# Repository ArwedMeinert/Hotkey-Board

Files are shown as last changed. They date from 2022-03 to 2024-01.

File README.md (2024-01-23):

# Hotkey-Board
All the needed Information for the Hotkey-Board
It includes the Schematics of the Hardware, the PCB- Layout and the Code for the actual microcontroller. 
Feel free to make your own changes and improve on what’s already there. 
All the uploaded Files (excluding the libraries in the Arduino IDE) were created by me.

After the design of the PCB, I got it made and soldert all parts on it. Luckily, everything worked at the first try.

The PCB of the Hotkey Board

Each button can be individually programmed. You can add more than one profile and add an individual colour to each profile (every button is individually backlit and be individually addressed). A button press gets visualized by the sudden change of colour, that then fades back to the standard colour of the profile within 200 ms (this also helps with the debounce time of the buttons).

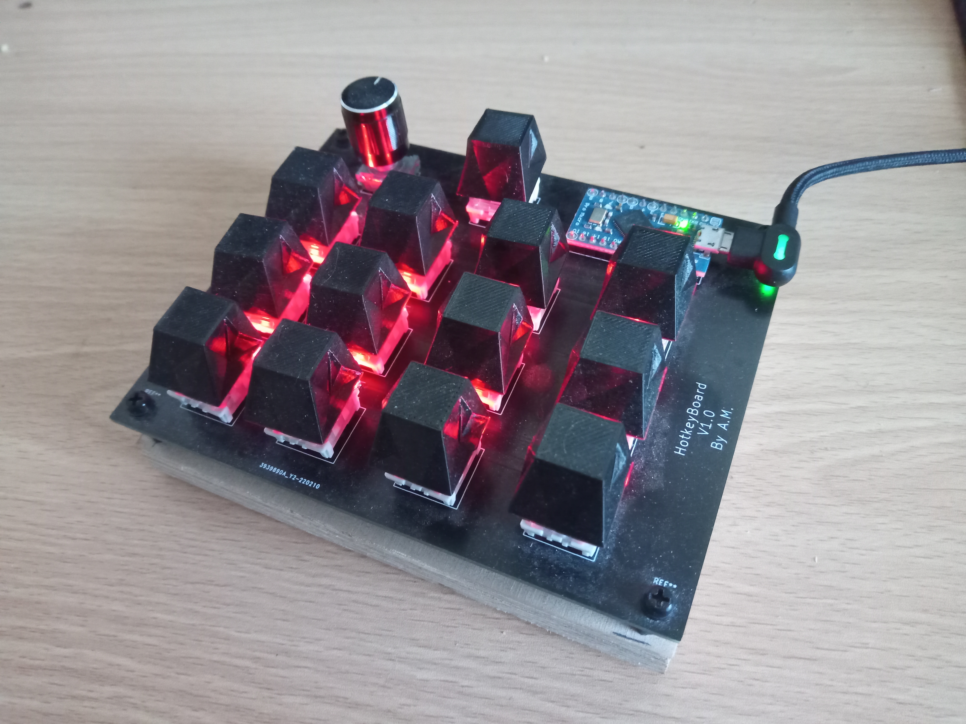
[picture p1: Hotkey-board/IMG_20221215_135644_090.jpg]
The PCB of the Hotkey Board


This version of the Hotkey-Board doesn't support anti-ghosting (using diodes for the button matrix). This could be an improvement left for a second version as well as a little OLED display to display various functions of the keys. 
## Case
After a few months in use I descided to add a case for the pcb to make it easier to carry around (and because I got access to a 3D Printer).

Case of the Board

All the files are available to download. The case now also includes holes for the hinges as well as magnets embedded in the lid to make it stay closed but still easy enough to open.

Case with the Board turned on

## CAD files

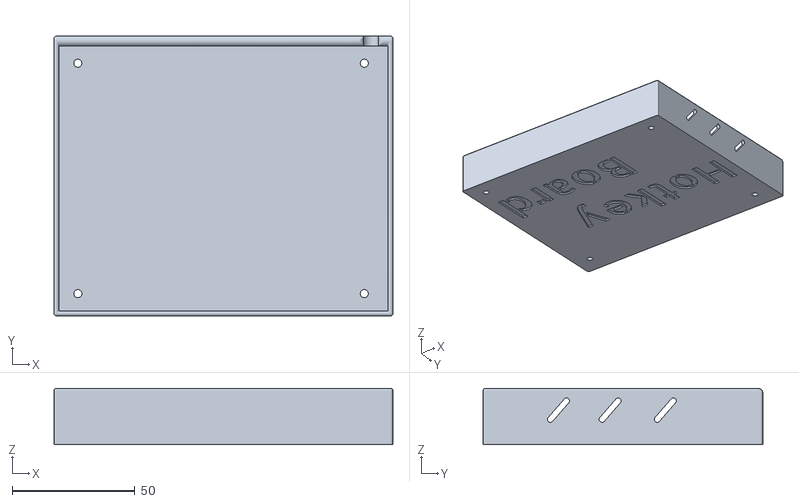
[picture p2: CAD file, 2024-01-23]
HotkeyBoard Case/Part Studio 1 - Part 2.stl
138.3 x 114.1 x 23.0

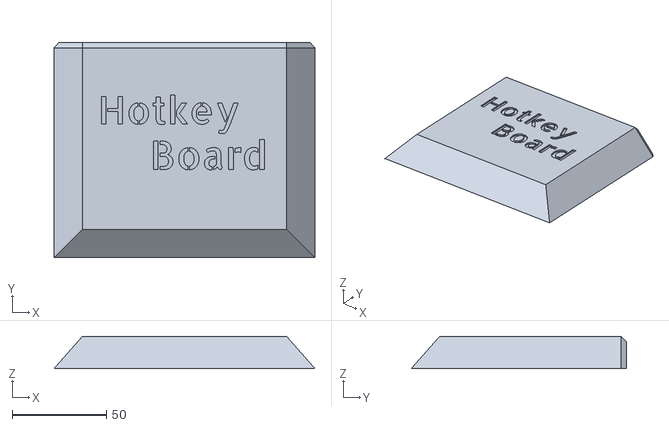
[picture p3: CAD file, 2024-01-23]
HotkeyBoard Case/LowerPart.stl
138.3 x 114.1 x 17.0

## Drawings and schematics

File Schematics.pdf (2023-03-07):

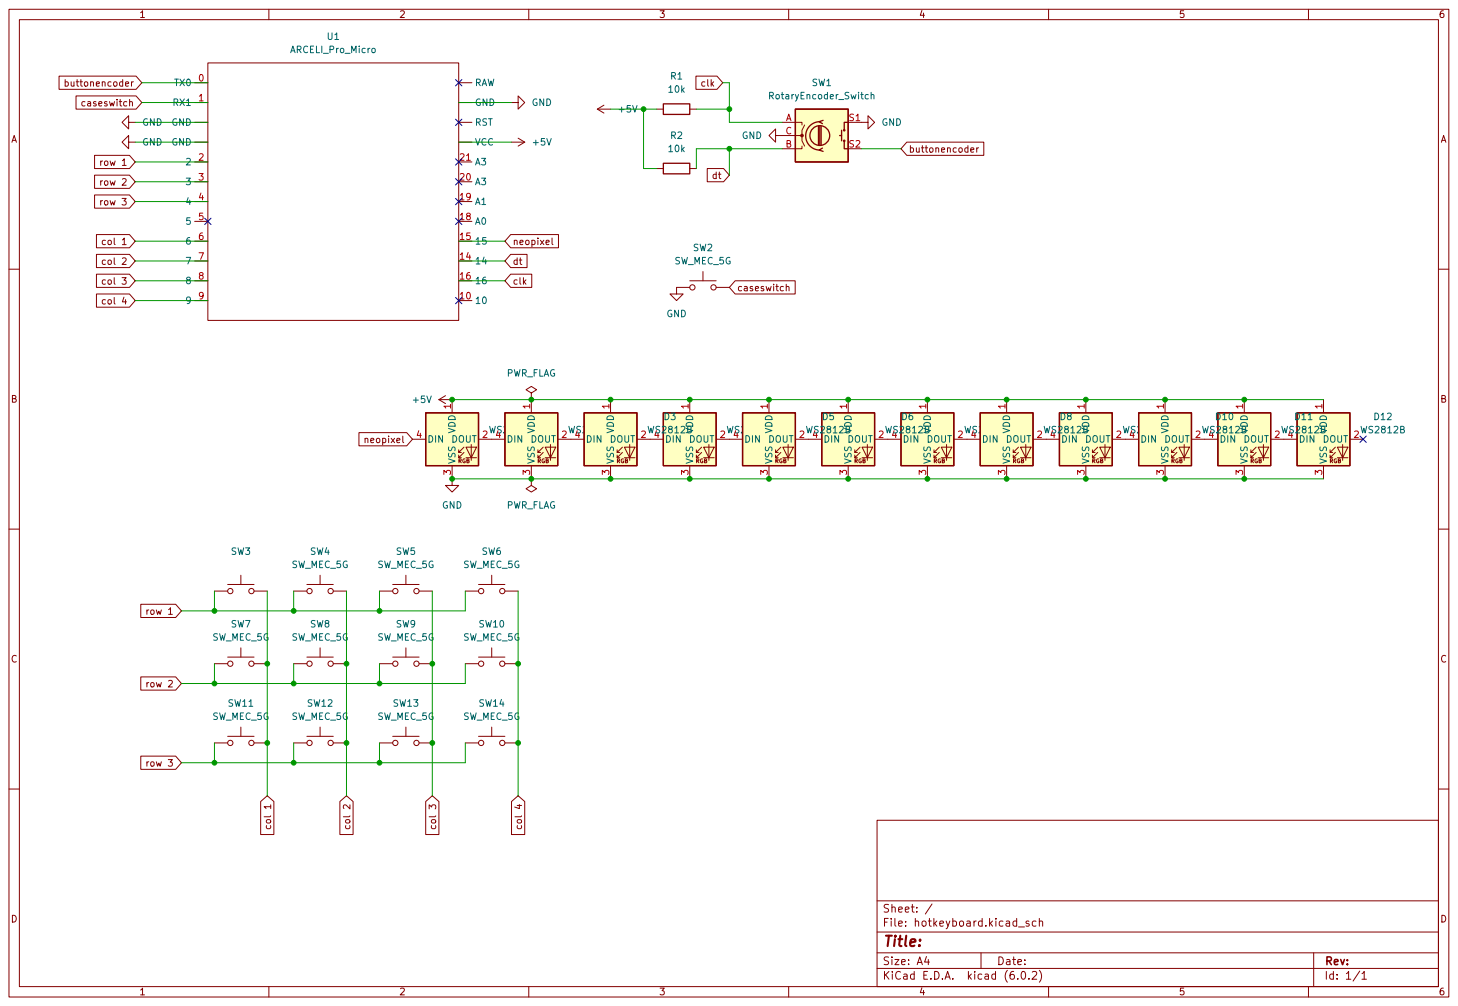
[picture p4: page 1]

3 DIN 4 D3 WS2812B GND GND GND
GND

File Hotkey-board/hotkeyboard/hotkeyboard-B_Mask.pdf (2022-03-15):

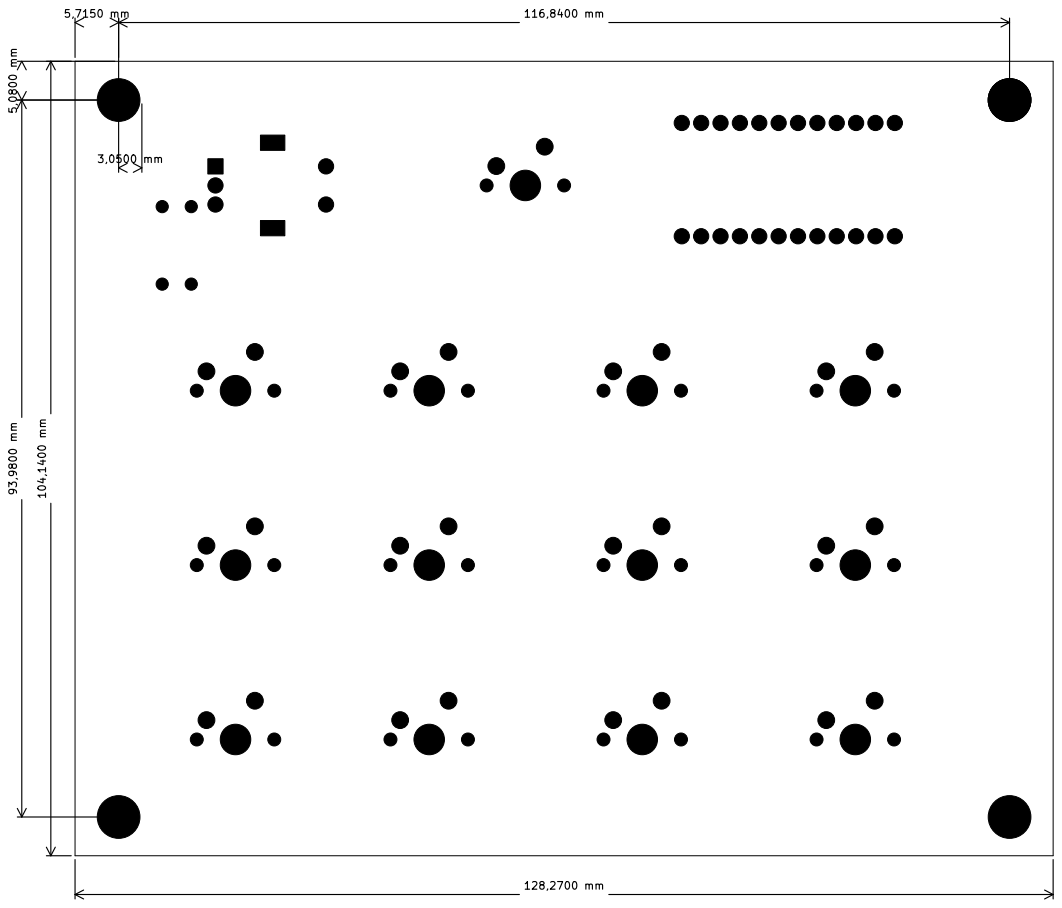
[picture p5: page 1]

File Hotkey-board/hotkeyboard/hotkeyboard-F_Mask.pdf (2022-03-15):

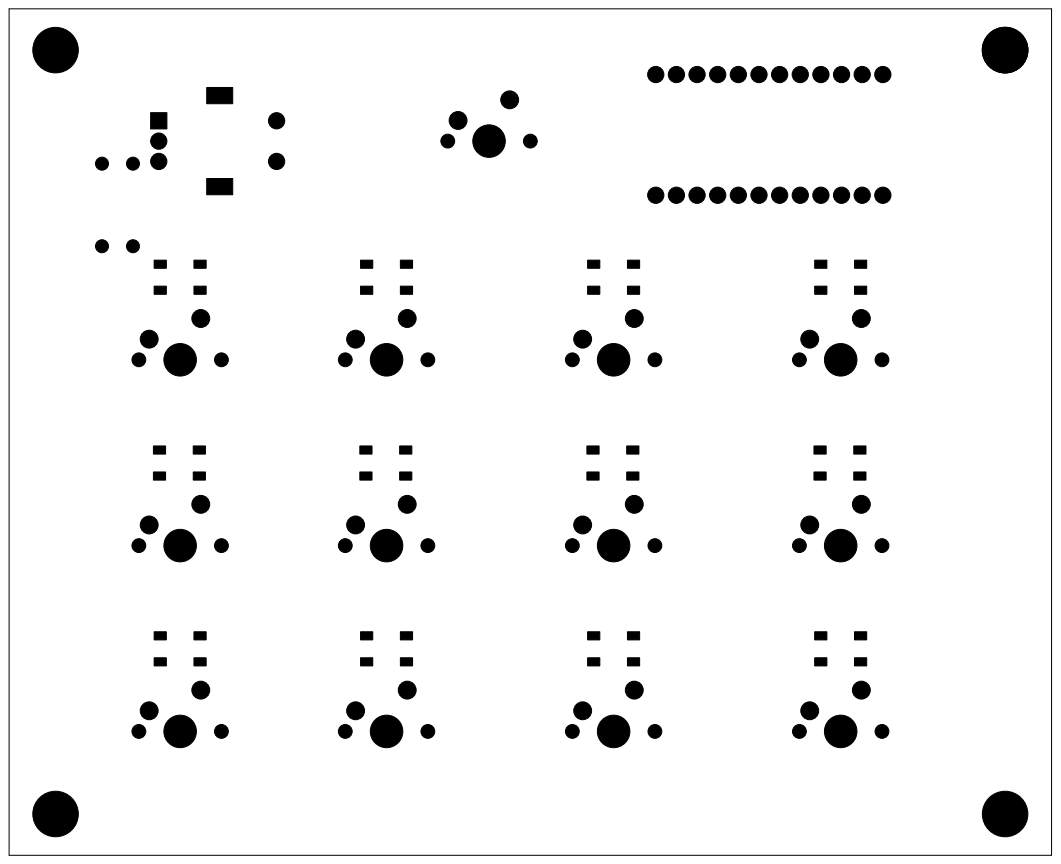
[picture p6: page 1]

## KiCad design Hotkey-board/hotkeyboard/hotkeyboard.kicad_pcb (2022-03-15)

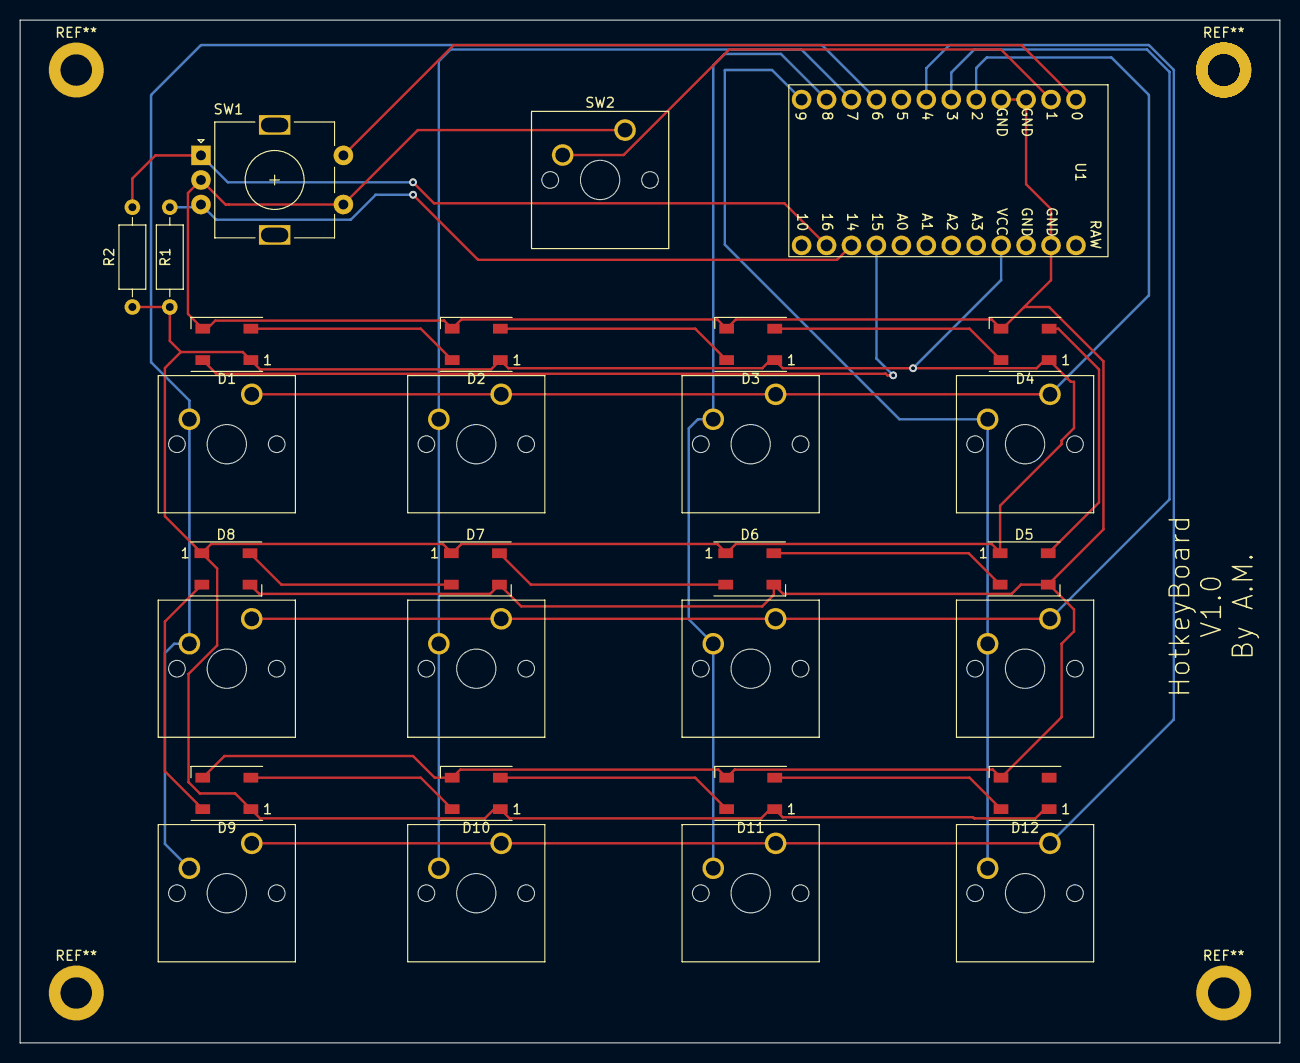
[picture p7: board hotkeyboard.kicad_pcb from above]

Board: 2 copper layers, 128.3 x 104.1 mm, 17 parts (0 on the bottom side), 18 nets.

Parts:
D1, D2, D3, D4, D5, D6, D7, D8, D9, D10, D11, D12: WS2812B; LED_WS2812B_PLCC4_5.0x5.0mm_P3.2mm
R1, R2: R_Axial_DIN0207_L6.3mm_D2.5mm_P10.16mm_Horizontal
SW1: RotaryEncoder_Switch; RotaryEncoder_Alps_EC11E-Switch_Vertical_H20mm
SW2: SW_MEC_5G; SW_Cherry_MX_1.00u_PCB
U1: ARCELI_Pro_Micro; ARCELI ATmega32U4

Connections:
+5V: D1.1 (VDD), D2.1 (VDD), D3.1 (VDD), D4.1 (VDD), D5.1 (VDD), D6.1 (VDD), D7.1 (VDD), D8.1 (VDD), D9.1 (VDD), D10.1 (VDD), D11.1 (VDD), D12.1 (VDD), R1.1, R2.1, U1.VCC
GND: D1.3 (VSS), D2.3 (VSS), D3.3 (VSS), D4.3 (VSS), D5.3 (VSS), D6.3 (VSS), D7.3 (VSS), D8.3 (VSS), D9.3 (VSS), D10.3 (VSS), D11.3 (VSS), D12.3 (VSS), SW1.C, SW1.S1, SW2.1, U1.GND
unnamed: D1.2 (DOUT), D2.4 (DIN)
unnamed: D2.2 (DOUT), D3.4 (DIN)
unnamed: D3.2 (DOUT), D4.4 (DIN)
unnamed: D4.2 (DOUT), D5.4 (DIN)
unnamed: D5.2 (DOUT), D6.4 (DIN)
unnamed: D6.2 (DOUT), D7.4 (DIN)
unnamed: D7.2 (DOUT), D8.4 (DIN)
unnamed: D8.2 (DOUT), D9.4 (DIN)
unnamed: D10.2 (DOUT), D11.4 (DIN)
unnamed: D9.2 (DOUT), D10.4 (DIN)
unnamed: D11.2 (DOUT), D12.4 (DIN)
buttonencoder: SW1.S2, U1.0 (TX0)
caseswitch: SW2.2, U1.1 (RX1)
clk: R2.2, SW1.A, U1.16
dt: R1.2, SW1.B, U1.14
neopixel: D1.4 (DIN), U1.15

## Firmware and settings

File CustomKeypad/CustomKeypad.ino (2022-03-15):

#include <Encoder.h>
#include <Mouse.h>
#include <Keyboard.h>
#include <Keypad.h>
#include <Adafruit_NeoPixel.h>
#define PIXEL_PIN    15
#define enablePin 10
#define PIXEL_COUNT 12
Adafruit_NeoPixel pixels(PIXEL_COUNT, PIXEL_PIN, NEO_GRB + NEO_KHZ800);
const int CLK = 16;      // Definition der Pins. CLK an D6, DT an D5.
const int DT = 14;
const int SW = 1;       // Der Switch wird mit Pin D2 Verbunden. ACHTUNG : Verwenden Sie einen interrupt-Pin!
long altePosition = -999;
Encoder meinEncoder(DT, CLK);
const byte COLS = 4;
const byte ROWS = 3; //four rows
//define the cymbols on the buttons of the keypads
char hexaKeys[ROWS][COLS] = {
  {'1', '2', '3', '4'},
  {'5', '6', '7', '8'},
  {'9', 'A', 'B', 'C'}
};
byte rowPins[ROWS] = {2, 3, 4}; //connect to the row pinouts of the keypad
byte colPins[COLS] = {6, 7, 8, 9}; //connect to the column pinouts of the keypad

//initialize an instance of clmakeeymapass NewKeypad
Keypad customKeypad = Keypad( makeKeymap(hexaKeys), rowPins, colPins, ROWS, COLS);
#define modechange 0
int casenr;
#define caseanz 2
long neuePosition;
char customKey;
bool switched;
void setup() {
  pixels.begin();
  Serial.begin(6600);
  pinMode(enablePin, INPUT_PULLUP);
  pinMode(SW, INPUT_PULLUP);
  pinMode(modechange, INPUT_PULLUP);

  // attachInterrupt(digitalPinToInterrupt(modechange), InterruptCase, FALLING);
  Mouse.begin();
  Keyboard.begin();
  int casenr = 1;
  switched = false;
}

void loop() {
  if (digitalRead(modechange) == LOW) {
    casenr = casenr + 1;
    if (casenr > caseanz) {
      casenr = 1;
    }
    switched = true;

  }
  if (enablePin == LOW) {
    Mouse.end();
    Keyboard.end();
  }
  if (casenr == 1) {
    int normaleFarbe1[] = {50, 0, 0};
    int gedrueckteFarbe1[] = {0, 50, 0};
    for (int i = 0; i < PIXEL_COUNT; i++) {
      pixels.setPixelColor(i, pixels.Color(normaleFarbe1[0], normaleFarbe1[1], normaleFarbe1[2]));
    }
    attachInterrupt(digitalPinToInterrupt(SW), Interrupt0, FALLING);
    neuePosition = meinEncoder.read();
    if (neuePosition != altePosition) { //Drehen des Encoders Mappen
      if (neuePosition > altePosition) {
        Mouse.move(0, 0, 1);            //Encoder nach links drehen
      }
      else {
        Mouse.move(0, 0, - 1);          //Encoder nach rechts drehen
      }
      altePosition = neuePosition;
    }
    customKey = customKeypad.getKey();

    if (customKey == '1') {
      Keyboard.press(KEY_LEFT_CTRL);
      Keyboard.press('c');
      fading(0, normaleFarbe1, gedrueckteFarbe1, 200);
      Keyboard.releaseAll();
    } else if (customKey == '2') {
      Keyboard.press(KEY_LEFT_CTRL);
      Keyboard.press('v');
      fading(1, normaleFarbe1, gedrueckteFarbe1, 200);
      Keyboard.releaseAll();
    } else if (customKey == '3') {
      Keyboard.press(KEY_LEFT_CTRL);
      Keyboard.press('u');
      fading(2, normaleFarbe1, gedrueckteFarbe1, 200);
      Keyboard.releaseAll();
    } else if (customKey == '4') {
       Keyboard.press(KEY_LEFT_ALT);
      Keyboard.press(225);
       Keyboard.press(227);
       Keyboard.press(228);
      fading(3, normaleFarbe1, gedrueckteFarbe1, 200);
      Keyboard.releaseAll();
    } else if (customKey == '5') {
     Keyboard.press(KEY_LEFT_CTRL);
       Keyboard.press(KEY_RIGHT_SHIFT);
       Keyboard.press('m');
      fading(7, normaleFarbe1, gedrueckteFarbe1, 200);
      Keyboard.releaseAll();
    } else if (customKey == '6') {
      Keyboard.print("MODE0");
      fading(6, normaleFarbe1, gedrueckteFarbe1, 200);
      Keyboard.releaseAll();
    } else if (customKey == '7') {
      Keyboard.print("MODE0");
      fading(5, normaleFarbe1, gedrueckteFarbe1, 200);
      Keyboard.releaseAll();
    } else if (customKey == '8') {
      Keyboard.print("MODE0");
      fading(4, normaleFarbe1, gedrueckteFarbe1, 200);
      Keyboard.releaseAll();
    } else if (customKey == '9') {
      Keyboard.write(22);
      fading(8, normaleFarbe1, gedrueckteFarbe1, 200);
      Keyboard.releaseAll();
    } else if (customKey == 'A') {
      Keyboard.print("MODE0");
      fading(9, normaleFarbe1, gedrueckteFarbe1, 200);
      Keyboard.releaseAll();
    } else if (customKey == 'B') {
      Keyboard.print("MODE0");
      fading(10, normaleFarbe1, gedrueckteFarbe1, 200);
      Keyboard.releaseAll();
    } else if (customKey == 'C') {
      Keyboard.print("MODE0");
      fading(11, normaleFarbe1, gedrueckteFarbe1, 200);
      Keyboard.releaseAll();
    }
    pixels.show();
  } else if (casenr == 2) {
    int normaleFarbe2[] = {0, 0, 50};
    int gedrueckteFarbe2[] = {50, 50, };
    for (int i = 0; i < PIXEL_COUNT; i++) {
      pixels.setPixelColor(i, pixels.Color(normaleFarbe2[0], normaleFarbe2[1], normaleFarbe2[2]));
    }
    pixels.show();
    attachInterrupt(digitalPinToInterrupt(SW), Interrupt1, FALLING);
    neuePosition = meinEncoder.read();
    if (neuePosition != altePosition) { //Drehen des Encoders Mappen
      if (neuePosition > altePosition) {
        Mouse.move(0, 0, 1);            //Encoder nach links drehen
      }
      else {
        Mouse.move(0, 0, - 1);          //Encoder nach rechts drehen
      }
      altePosition = neuePosition;
    }
    customKey = customKeypad.getKey();
    if (customKey == '1') {
       Keyboard.press(KEY_LEFT_ALT);
      Keyboard.press(223);
      fading(0, normaleFarbe2, gedrueckteFarbe2, 200);
      Keyboard.releaseAll();
    } else if (customKey == '2') {
      Keyboard.press(KEY_LEFT_ALT);
      Keyboard.press(224);
      fading(1, normaleFarbe2, gedrueckteFarbe2, 200);
      Keyboard.releaseAll();
    } else if (customKey == '3') {
      Keyboard.press(KEY_LEFT_ALT);
      Keyboard.press(225);
      fading(2, normaleFarbe2, gedrueckteFarbe2, 200);
      Keyboard.releaseAll();
    } else if (customKey == '4') {
     Keyboard.press(KEY_LEFT_ALT);
     Keyboard.press(KEY_LEFT_CTRL);
      Keyboard.press(226);
      fading(3, normaleFarbe2, gedrueckteFarbe2, 200);
      Keyboard.releaseAll();
    } else if (customKey == '5') {
      Keyboard.press(KEY_LEFT_ALT);
      Keyboard.press(KEY_LEFT_CTRL);
      Keyboard.press(227);
      fading(7, normaleFarbe2, gedrueckteFarbe2, 200);
      Keyboard.releaseAll();
    } else if (customKey == '6') {
      Keyboard.press(KEY_LEFT_ALT);
      Keyboard.press(KEY_LEFT_CTRL);
      Keyboard.press(228);
      fading(6, normaleFarbe2, gedrueckteFarbe2, 200);
      Keyboard.releaseAll();
    } else if (customKey == '7') {
      Keyboard.press(KEY_LEFT_ALT);
      Keyboard.press(KEY_LEFT_CTRL);
      Keyboard.press(229);
      fading(5, normaleFarbe2, gedrueckteFarbe2, 200);
      Keyboard.releaseAll();
    } else if (customKey == '8') {
      Keyboard.press(KEY_LEFT_ALT);
      Keyboard.press(KEY_LEFT_CTRL);
      Keyboard.press(230);
      fading(4, normaleFarbe2, gedrueckteFarbe2, 200);
      Keyboard.releaseAll();
    } else if (customKey == '9') {
      Keyboard.press(KEY_LEFT_ALT);
      Keyboard.press(KEY_LEFT_CTRL);
      Keyboard.press(231);
      fading(8, normaleFarbe2, gedrueckteFarbe2, 200);
      Keyboard.releaseAll();
    } else if (customKey == 'A') {
      Keyboard.press(KEY_LEFT_ALT);
      Keyboard.press(KEY_LEFT_CTRL);
      Keyboard.press(232);
      fading(9, normaleFarbe2, gedrueckteFarbe2, 200);
      Keyboard.releaseAll();
    } else if (customKey == 'B') {
      Keyboard.print("MODE1");
      fading(10, normaleFarbe2, gedrueckteFarbe2, 200);
      Keyboard.releaseAll();
    } else if (customKey == 'C') {
      Keyboard.print("MODE1");
      fading(11, normaleFarbe2, gedrueckteFarbe2, 200);
      Keyboard.releaseAll();
    }
    pixels.show();
  }
  if (switched == true) {
    delay(300);
    switched = false;
  }
}



void Interrupt0() {
  Mouse.click();
}
void Interrupt1() {
  Mouse.press(MOUSE_RIGHT);
  Mouse.release(MOUSE_RIGHT);
}
//void InterruptCase(){
// casenr=casenr+1;
//if (casenr>caseanz){
// casenr=1;
//}


//}

void fading(int pixel, int farbenormal[], int farbefade[], int zeit) {
  int t = zeit / 100;
  int rr;
  int gg;
  int bb;
  for (int s = 0; s < 100; s++) {
    rr = map(s, 0, 99, farbefade[0], farbenormal[0]);
    gg = map(s, 0, 99, farbefade[1], farbenormal[1]);
    bb = map(s, 0, 99, farbefade[2], farbenormal[2]);
    pixels.setPixelColor(pixel, pixels.Color(rr, gg, bb));
    pixels.show();
    delay(t);
  }
}
